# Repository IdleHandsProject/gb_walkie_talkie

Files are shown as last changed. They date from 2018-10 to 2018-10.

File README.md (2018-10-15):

# Ghost Bros Walkie-Talkie
## An open source "Fake" walkie-talkie for Fake Ghost Tours made by my friends in Vancouver.

When I say "Fake" walkie-talkie, what I mean is that this walkie-talkie does not do two way commincation. It actually doesn't even do one way communication(if you don't count the gps). 
This walkie-talkie was designed for my friends at Fake Ghost Tours [FakeGhostTours.com](http://fakeghosttours.com) - real friends not fake friends.

The purpose of the walkie-talkie is to be a GPS guided audio tour of fake ghost stories in Vancouver, British Columbia. 
Watch the video to see how it works, and why it was made. 
https://youtu.be/CiPm3to5vCE

Build Vid (https://youtu.be/CiPm3to5vCE)

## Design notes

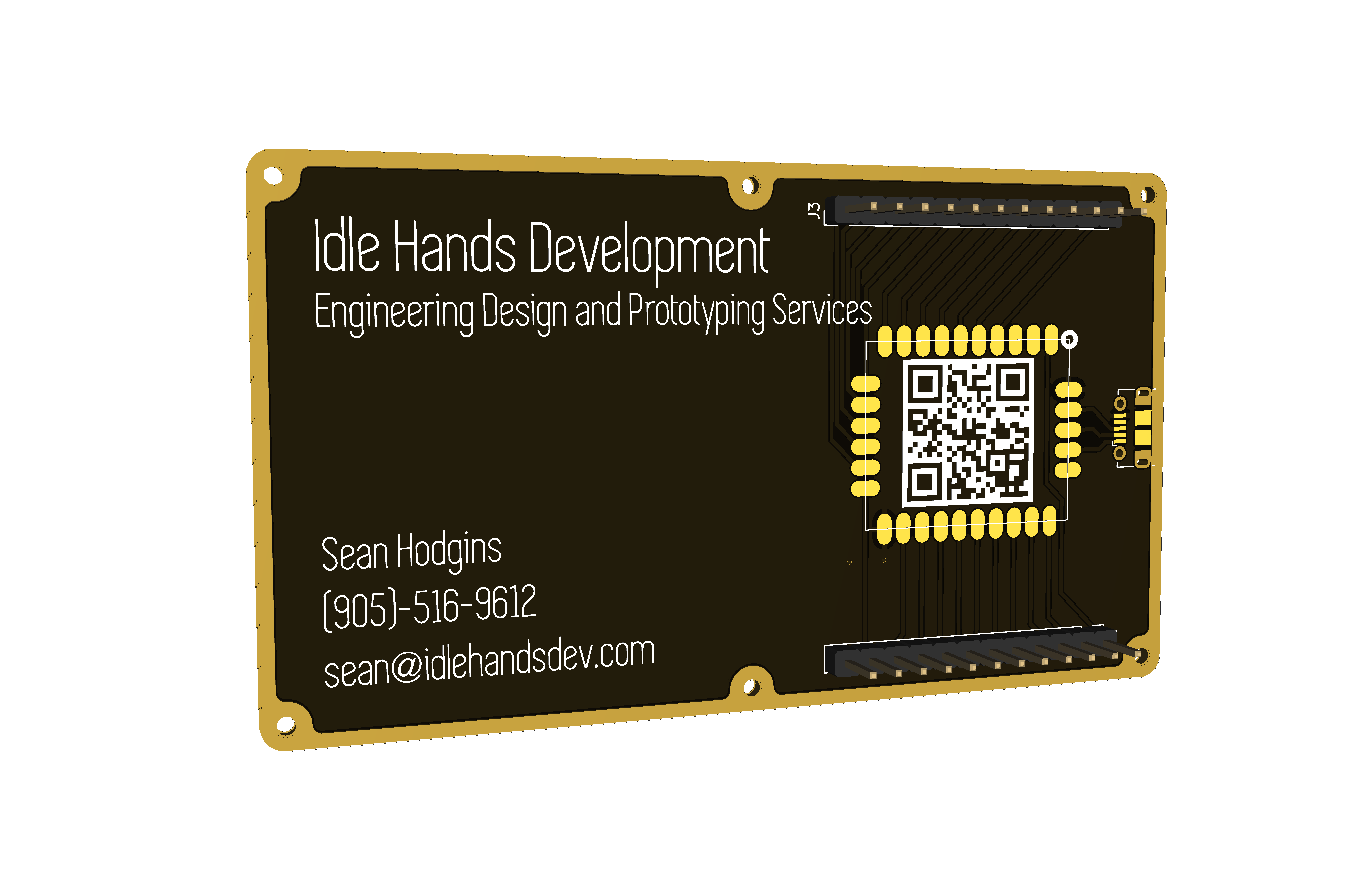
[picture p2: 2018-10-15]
CAD/images/bizcard.png

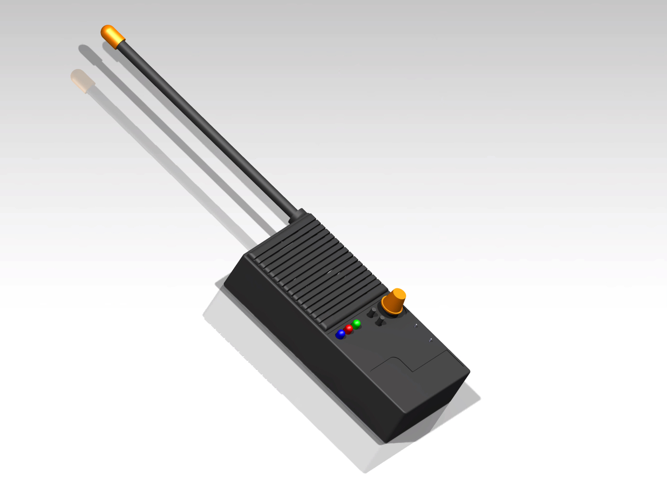
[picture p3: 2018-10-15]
CAD/images/GB_walkie.jpg

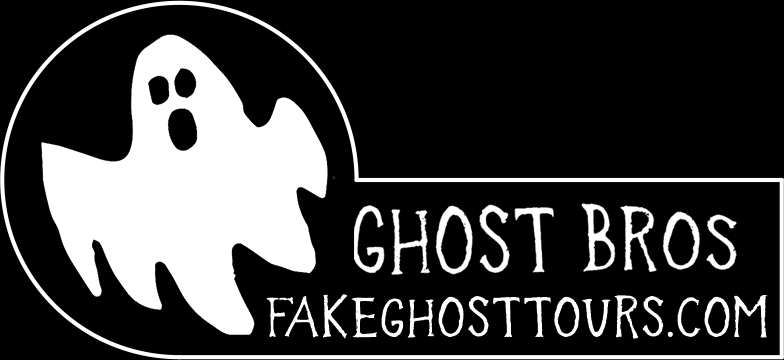
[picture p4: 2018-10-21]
CAD/Drawing/Sticker_Black.png

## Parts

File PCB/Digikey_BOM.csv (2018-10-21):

Manufacturer Part Number | Manufacturer | Digi-Key Part Number | Customer Reference | Reference Designator | Packaging | Part Status | Quantity | Description
BH3AAPC | MPD (Memory Protection Devices) | BH3AA-PC-ND | BT1 |  | Bulk | Active | 1 | BATTERY HOLDER AA 3 CELL PC PIN
CL21F104ZAANNNC | Samsung Electro-Mechanics | 1276-1286-1-ND | C1 C15 C17 C18 |  | Cut Tape (CT) | Active | 4 | CAP CER 0.1UF 25V Y5V 0805
CL21B103KBCNNNC | Samsung Electro-Mechanics | 1276-1078-1-ND | C5 C6 |  | Cut Tape (CT) | Active | 2 | CAP CER 10000PF 50V X7R 0805
CC0402MRX5R5BB106 | Yageo | 311-1729-1-ND | C16 |  | Cut Tape (CT) | Discontinued at Digi-Key | 1 | CAP CER 10UF 6.3V X5R 0402
TMK212BJ105KG-T | Taiyo Yuden | 587-1291-1-ND | C2 C9 C10 C12 C14 C19 C20 |  | Cut Tape (CT) | Active | 7 | CAP CER 1UF 25V X5R 0805
CC0805KRX7R9BB221 | Yageo | 311-1123-1-ND | C11 C13 |  | Cut Tape (CT) | Active | 2 | CAP CER 220PF 50V X7R 0805
EEE-FT0J221AR | Panasonic Electronic Components | P15078CT-ND | C7 C8 |  | Cut Tape (CT) | Active | 2 | CAP ALUM 220UF 20% 6.3V SMD
08051A220KAT2A | AVX Corporation | 478-3736-1-ND | C3 C4 |  | Cut Tape (CT) | Active | 2 | CAP CER 22PF 100V C0G/NP0 0805
35RASMT4BHNTRX | Switchcraft Inc. | SC1488-1-ND | J2 |  | Cut Tape (CT) | Active | 1 | CONN JACK STEREO 3.5MM SMD R/A
693072010801 | Wurth Electronics Inc. | 732-3820-1-ND | J3 |  | Cut Tape (CT) | Active | 1 | CONN MICRO SD CARD HINGED TYPE
614105150721 | Wurth Electronics Inc. | 732-5958-1-ND | J1 |  | Cut Tape (CT) | Active | 1 | CONN RCPT USB TYPE B
MMZ1608B121CTAH0 | TDK Corporation | 445-2164-1-ND | L1 L2 L3 L4 L5 |  | Cut Tape (CT) | Active | 5 | FERRITE BEAD 120 OHM 0603 1LN
GF0666M | CUI Inc. | GF0666M-ND | LS1 |  | Box | Active | 1 | SPEAKER 8OHM 500MW TOP PORT 83DB
CRCW0805100KJNEAC | Vishay Dale | 541-4164-1-ND | R2 R8 R9 R10 R11 R13 R17 |  | Cut Tape (CT) | Active | 7 | RES SMD 100K OHM 5% 1/8W 0805
RC0805JR-07100RL | Yageo | 311-100ARCT-ND | R4 R5 R6 R7 |  | Cut Tape (CT) | Active | 4 | RES SMD 100 OHM 5% 1/8W 0805
RC2012J103CS | Samsung Electro-Mechanics | 1276-5552-1-ND | R12 R15 R18 R19 R20 |  | Cut Tape (CT) | Active | 5 | RES SMD 10K OHM 5% 1/8W 0805
RC0805JR-071KL | Yageo | 311-1.0KARCT-ND | R1 R14 R16 |  | Cut Tape (CT) | Active | 3 | RES SMD 1K OHM 5% 1/8W 0805
RC0805JR-071ML | Yageo | 311-1.0MARCT-ND | R3 |  | Cut Tape (CT) | Active | 1 | RES SMD 1M OHM 5% 1/8W 0805
B3U-1000P | Omron Electronics Inc-EMC Div | SW1020CT-ND | RESET1 |  | Cut Tape (CT) | Active | 1 | SWITCH TACTILE SPST-NO 0.05A 12V
OS102011MS2QN1 | C&K | CKN9565-ND | SW5 |  | Bulk | Active | 1 | SWITCH SLIDE SPDT 100MA 12V
PEC11R-4115F-S0018 | Bourns Inc. | PEC11R-4115F-S0018-ND | SW1 |  | Tray | Active | 1 | ROTARY ENCODER MECHANICAL 18PPR
219-3MST | CTS Electrocomponents | CT2193MST-ND | SW6 |  | Tube | Active | 1 | SWITCH SLIDE DIP SPST 100MA 20V
MJTP1230D | APEM Inc. | 679-2432-ND | SW2 SW3 |  | Bulk | Active | 2 | SWITCH TACTILE SPST-NO 0.05A 12V
AP2112K-1.8TRG1 | Diodes Incorporated | AP2112K-1.8TRG1DICT-ND | U5 |  | Cut Tape (CT) | Active | 1 | IC REG LINEAR 1.8V 600MA SOT25
PAM8302AADCR | Diodes Incorporated | PAM8302AADCRDICT-ND | U3 |  | Cut Tape (CT) | Active | 1 | IC AMP AUDIO 2.5W CLASS D 8SOIC
ABM8G-12.288MHZ-4Y-T3 | Abracon LLC | 535-10902-1-ND | Y1 |  | Cut Tape (CT) | Active | 1 | CRYSTAL 12.2880MHZ 10PF SMD
3314J-1-103E | Bourns Inc. | 3314J-103ECT-ND | RV1 |  | Cut Tape (CT) | Active | 1 | TRIMMER 10K OHM 0.25W J LEAD TOP
151051VS04000 | Wurth Electronics Inc. | 732-5017-ND | GLED |  | Bulk | Active | 1 | LED GREEN DIFFUSED 5MM ROUND T/H
151051RS11000 | Wurth Electronics Inc. | 732-5016-ND | RLED |  | Bulk | Active | 1 | LED RED DIFFUSED 5MM ROUND T/H
151051BS04000 | Wurth Electronics Inc. | 732-5015-ND | BLED |  | Bulk | Active | 1 | LED BLUE DIFFUSED 5MM ROUND T/H

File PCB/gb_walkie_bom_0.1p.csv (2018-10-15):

Component | Description | Part | References | Value | Footprint | Quantity Per PCB | Datasheet | Digikey Part No. | Digikey Part No. | Field8 | Field4 | Field7 | Field6 | Field5
1 | Battery (multiple cells) | Battery | BT1 | Battery | BatteryHolder_BH3AAPC_3xAA | 1 | ~ | BH3AA-PC-ND
2 | Unpolarized capacitor | C_Small | C1 C15 C17 C18 | 0.1uF | C_0805_2012Metric | 4 | ~ | 1276-1286-1-ND
3 | Unpolarized capacitor | C_Small | C5 C6 | 10nF | C_0805_2012Metric | 2 | ~ | 1276-1078-1-ND
4 | Unpolarized capacitor | C_Small | C16 | 10uF | C_0805_2012Metric | 1 | ~ | 311-1729-1-ND
5 | Unpolarized capacitor | C_Small | C2 C9 C10 C12 C14 C19 C20 | 1uF | C_0805_2012Metric | 7 | ~ | 587-1291-1-ND
6 | Unpolarized capacitor | C_Small | C11 C13 | 220pF | C_0805_2012Metric | 2 | ~ | 311-1123-1-ND
7 | Polarised capacitor | CP1_Small | C7 C8 | 220uF | CP_Elec_5x5.3 | 2 | ~ | P15078CT-ND
8 | Unpolarized capacitor | C_Small | C3 C4 | 22pF | C_0805_2012Metric | 2 | ~ | 478-3736-1-ND
9 | LED generic | LED | D1 D2 D3 | LED | LED_D5.0mm | 3 | ~
10 | D Audio Jack, 3 Poles (Stereo / TRS), Grounded Sleeve, Switched Poles (Normalling) | AudioJack3_Ground_Switch | J2 | HPJACK | Jack_3.5mm_35RASMT4BHNTRX_Horizontal | 1 | ~ | SC1488-1-ND
11 | Micro SD Card Socket | Micro_SD_Card | J3 | Micro_SD_Card | microSD_HC_Wuerth_693072010801 | 1 | http://katalog.we-online.de/em/datasheet/693072010801.pdf | 732-3820-1-ND
12 | USB mini/micro connector | USB_OTG | J1 | USB_OTG | USB_Micro-B_Wuerth_614105150721_Vertical | 1 | ~ | 732-5958-1-ND
13 | Solder Jumper, 3-pole, open | SolderJumper_3_Open | JP8 | 1v8EN | SolderJumper-3_P1.3mm_Open_RoundedPad1.0x1.5mm | 1 | ~
14 | Solder Jumper, 3-pole, open | SolderJumper_3_Open | JP6 | MP3RXSEL | SolderJumper-3_P1.3mm_Open_RoundedPad1.0x1.5mm | 1 | ~
15 | Jumper, normally open | Jumper_NO_Small | JP4 JP5 JP7 | RST | SolderJumper-2_P1.3mm_Open_RoundedPad1.0x1.5mm | 3 | ~
16 | Ferrite bead | Ferrite_Bead | L1 L2 | AFLTR | L_0805_2012Metric | 2 | ~ | 445-2164-1-ND
17 | Ferrite bead | Ferrite_Bead | L3 | GFLTR | L_0805_2012Metric | 1 | ~ | 445-2164-1-ND
18 | Ferrite bead | Ferrite_Bead | L4 L5 | SPFLTR | L_0805_2012Metric | 2 | ~ | 445-2164-1-ND
19 | speaker | Speaker | LS1 | Speaker | TerminalBlock_MetzConnect_Type059_RT06302HBWC_1x02_P3.50mm_Horizontal | 1 | ~
20 | Resistor, small symbol | R_Small | R2 R8 R9 R10 R11 R13 R17 | 100K | R_0805_2012Metric | 7 | ~ |  | 541-4164-1-ND
21 | Resistor, small symbol | R_Small | R4 R5 R6 R7 | 100R | R_0805_2012Metric | 4 | ~ |  | 311-100ARCT-ND
22 | Resistor, small symbol | R_Small | R12 R15 R18 R19 R20 | 10K | R_0805_2012Metric | 5 | ~ |  | 1276-5552-1-ND
23 | Resistor, small symbol | R_Small | R1 R14 R16 | 1K | R_0805_2012Metric | 3 | ~ | 311-1.0KARCT-ND
24 | Resistor, small symbol | R_Small | R3 | 1M | R_0805_2012Metric | 1 | ~ |  | 311-1.0MARCT-ND
25 | Push button switch, generic, two pins | SW_Push | RESET1 | RESET | SW_SPST_B3U-1000P | 1 |  | SW1020CT-ND
26 | Potentiometer | R_POT | RV1 | R_POT | Potentiometer_Bourns_3314J_Vertical | 1 | ~ | 445-2164-1-ND
27 | Switch, single pole double throw | SW_SPDT | SW5 | POWER | SW_CuK_OS102011MA1QN1_SPDT_Angled | 1 |  | CKN9565-ND
28 | Rotary encoder, dual channel, incremental quadrate outputs, with switch | Rotary_Encoder_Switch | SW1 | Rotary_Encoder_Switch | RotaryEncoder_Alps_EC11E-Switch_Vertical_H20mm | 1 | ~ | PEC11R-4115F-S0018-ND
29 | 3x DIP Switch, Single Pole Single Throw (SPST) switch, small symbol | SW_DIP_x03 | SW6 | SW_DIP_x03 | SW_DIP_SPSTx03_Slide_6.7x9.18mm_W6.73mm_P2.54mm_LowProfile_JPin | 1 |  | CT2193MST-ND
30 | Push button switch, generic, two pins | SW_Push | SW2 SW3 | SW_Push | SW_PUSH_6mm_H13mm | 2
31 | 300mA low dropout linear regulator, shutdown pin, 2.5V-6V input voltage, 1.8V fixed positive output, SOT-23-5 package | AP2127K-1.8 | U5 | AP2127K-1.8 | SOT-23-5 | 1 | https://www.diodes.com/assets/Datasheets/AP2127.pdf | AP2112K-1.8TRG1DICT-ND
32 |  | CODECODER-VS1053B(LQFP48) | U2 | CODECODER-VS1053B(LQFP48) | LQFP-48_7x7mm_P0.5mm | 1 | VS1053B MP3/WAV/OGG/MIDI Player & Recorder _CODEC_ Chip |  |  | VS1053B-L | Unavailable | None | VLSI | LQFP-48 VLSI
33 |  | FGPMM0PA6H | U4 | FGPMM0PA6H | FGPMMOPA6H | 1
34 | 2.5W Filterless Class-D Mono Audio Amplifier, SOIC-8 | PAM8302AAD | U3 | PAM8302AAD | SOIC-8_3.9x4.9mm_P1.27mm | 1 | https://www.diodes.com/assets/Datasheets/PAM8302A.pdf | PAM8302AADCRDICT-ND
35 |  | SAMD21_MOD | U1 | SAMD21_MOD | SAMD_HCC_G_FOOT | 1
36 | Four pin crystal (GND on pins 2 and 4), e.g. in SMD package | Crystal_GND24 | Y1 | 12.288MHz | crystal_fa128 | 1 | ~ | 535-10902-1-ND
Component Groups: | 36
Component Count: | 71
Fitted Components: | 71
Number of PCBs: | 1
Total components: | 71
Schematic Version: | 0.1p
Schematic Date: | 2018-10-01
BoM Date: | 10/10/2018 3:36:40 PM
Schematic Source: | \\HODGINSA-LAPTOP\Users\hodginsa\Documents\idlehandsdev\walkietalkie_ghostbros\PCB\gb_walkie.sch
KiCad Version: | Eeschema (5.0.0)

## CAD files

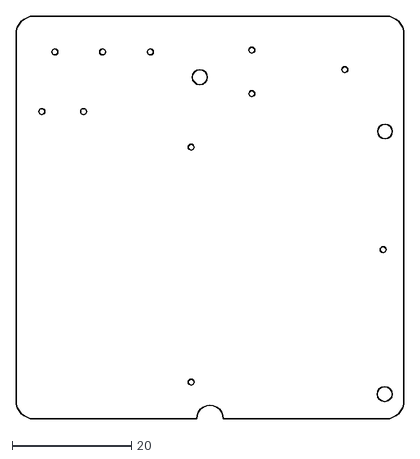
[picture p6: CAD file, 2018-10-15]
CAD/Drawing/PCB.dxf
65.0 x 67.5

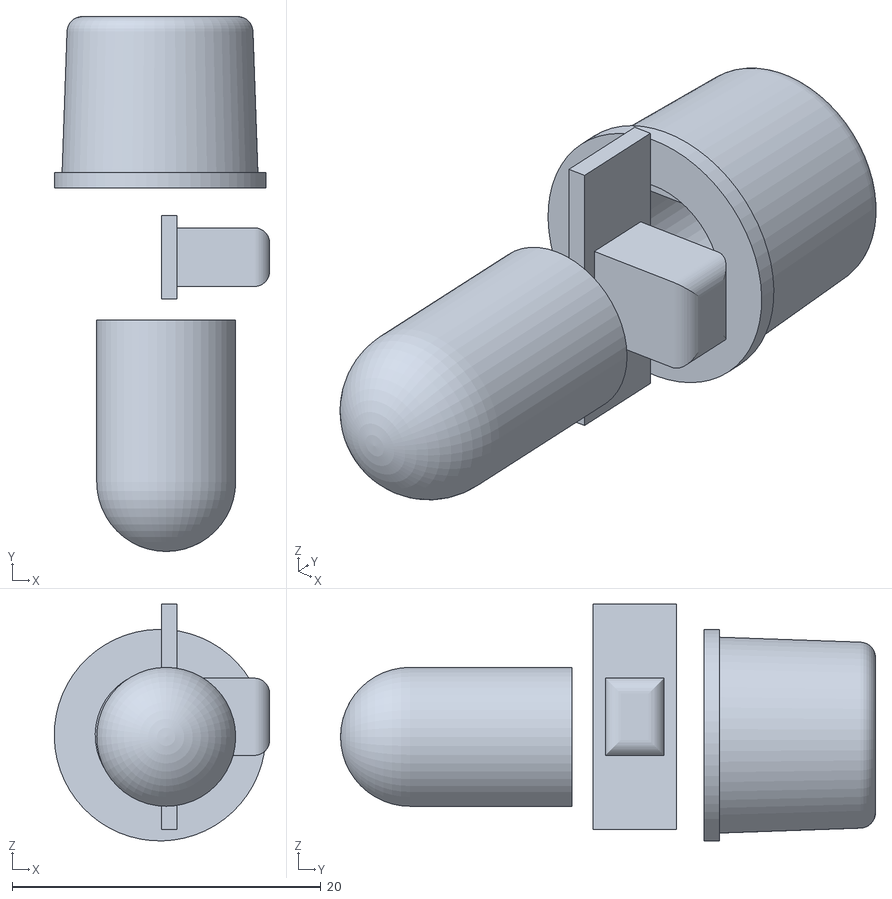
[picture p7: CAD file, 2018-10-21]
CAD/STL/Accessories.stl
14.0 x 34.7 x 15.3

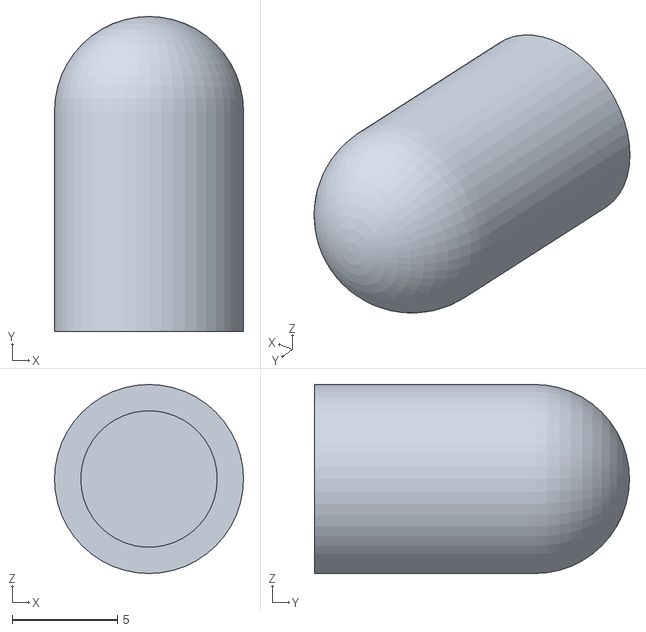
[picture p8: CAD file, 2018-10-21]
CAD/STL/Thingi/ANTCAP.stl
9.00 x 15.0 x 9.00

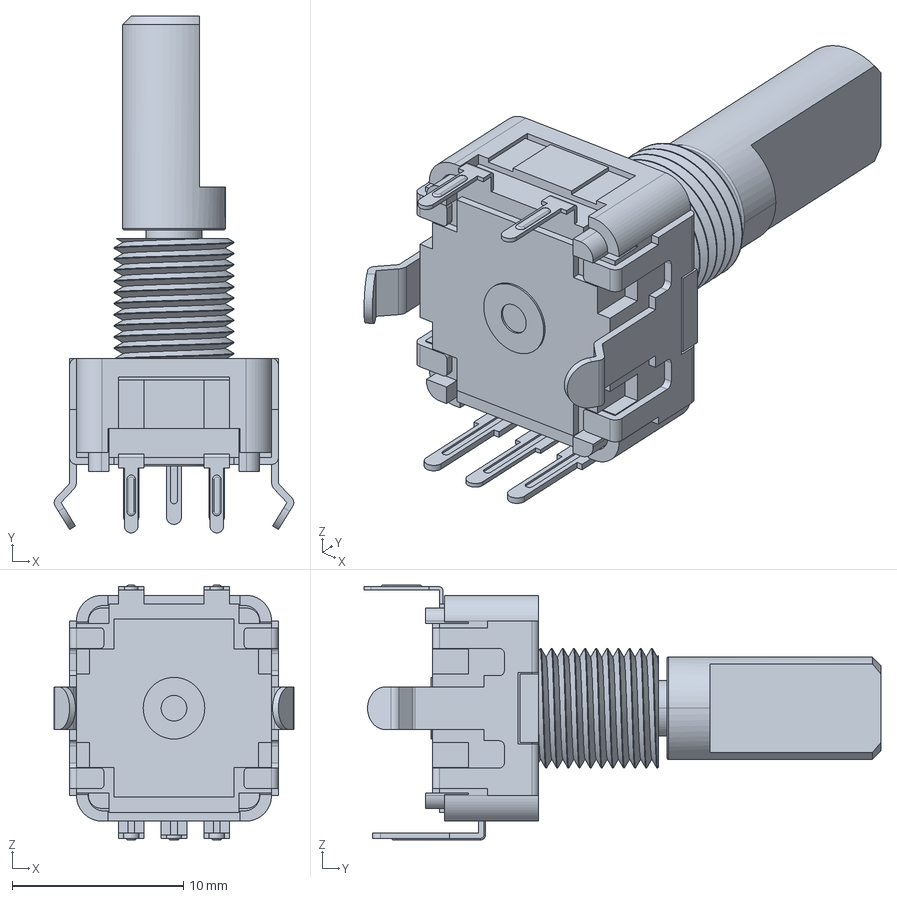
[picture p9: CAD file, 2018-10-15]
CAD/STP/pec11r-4x20f-sxxxx.stp
14.0 x 30.2 x 14.9 mm

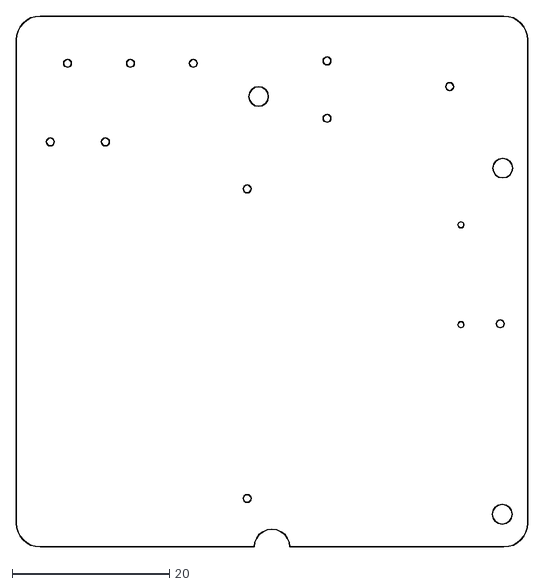
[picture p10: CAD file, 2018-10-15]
PCB/PCB.dxf
65.0 x 67.5

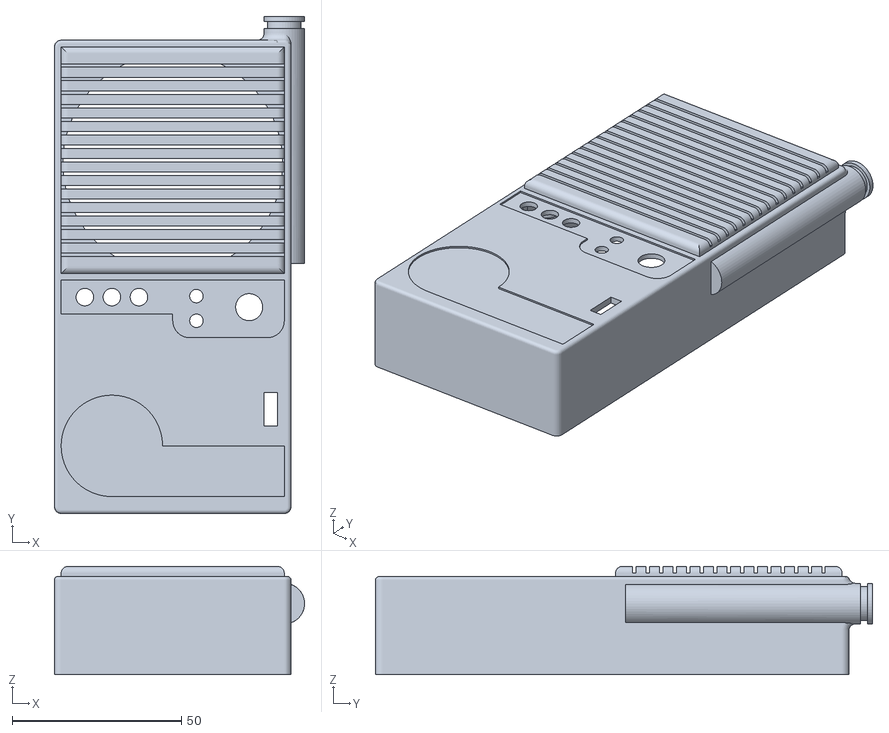
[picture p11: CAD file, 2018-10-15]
CAD/STL/FrontBody.stl
74.0 x 147.0 x 32.0

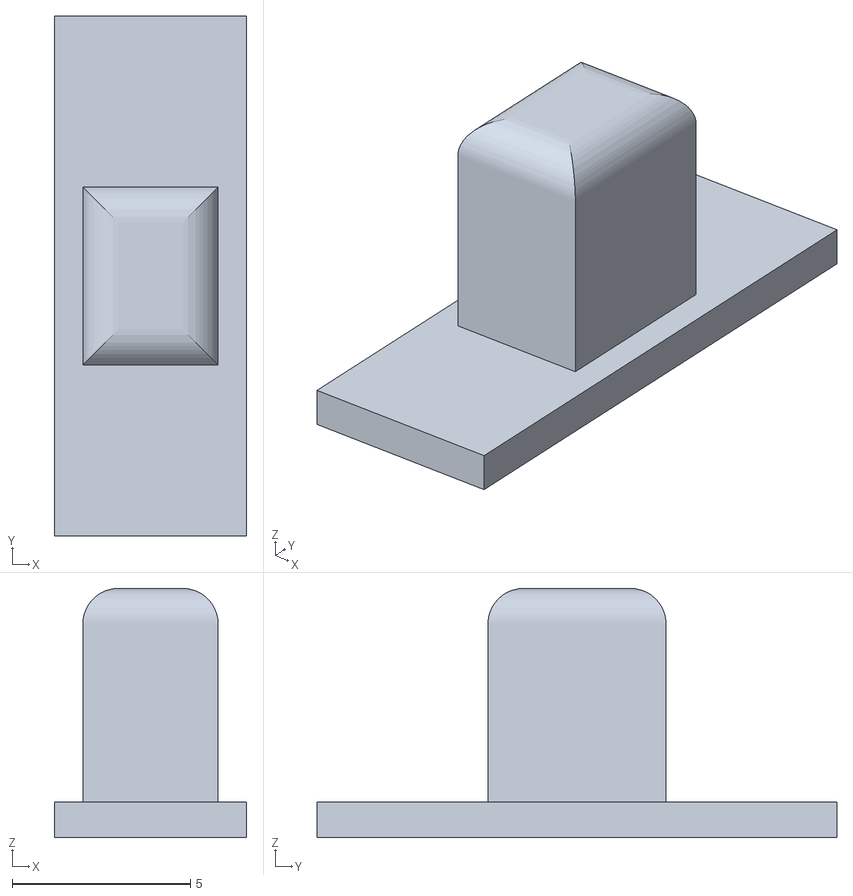
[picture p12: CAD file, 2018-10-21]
CAD/STL/Thingi/SwitchCap.stl
5.40 x 14.6 x 7.00

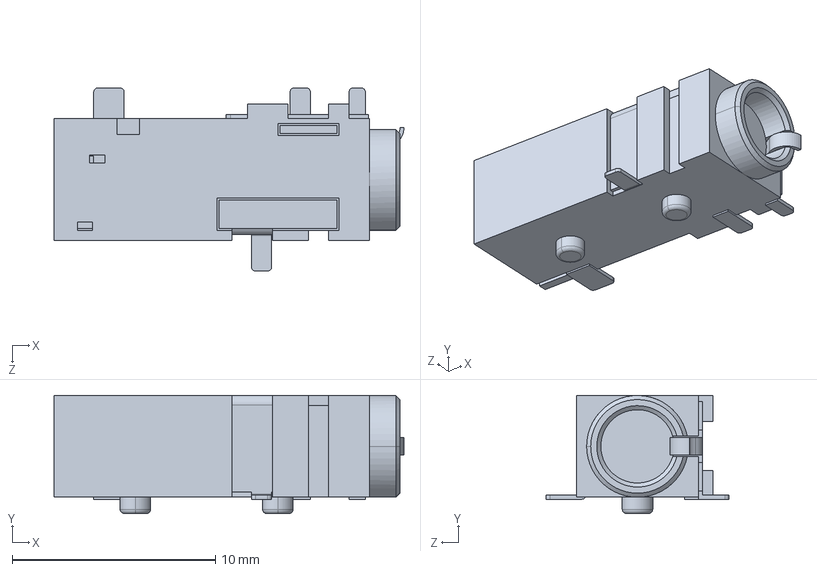
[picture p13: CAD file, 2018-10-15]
CAD/STP/CUI_SJ-43514-SMT-TR.step
17.2 x 5.80 x 9.00 mm

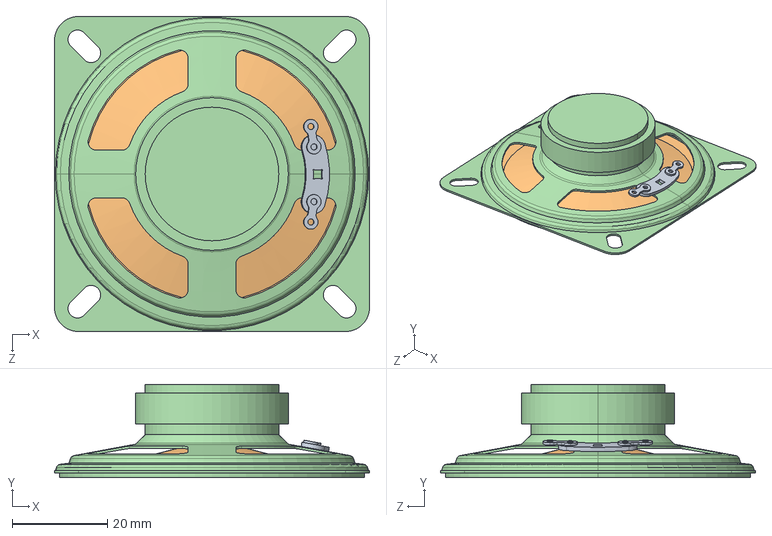
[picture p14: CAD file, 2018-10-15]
CAD/STP/CUI_GF0666M.step
66.0 x 19.5 x 66.0 mm

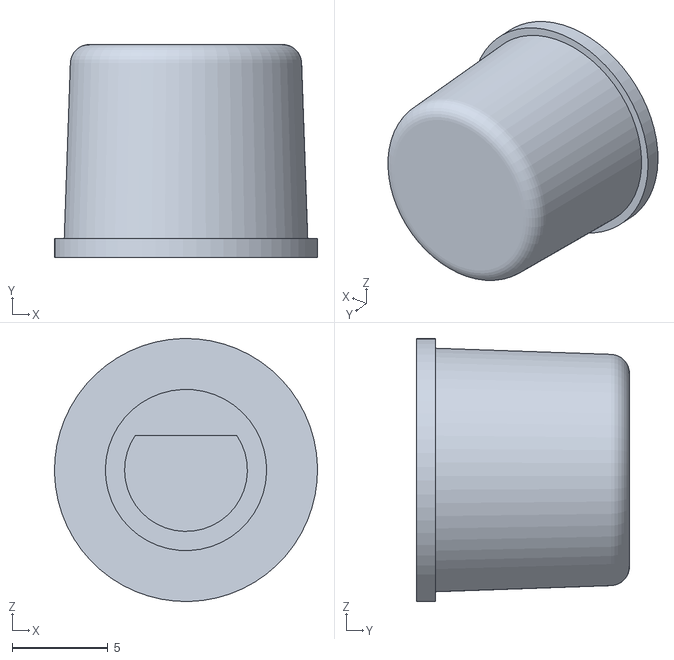
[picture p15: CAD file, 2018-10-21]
CAD/STL/Thingi/Knob.stl
13.7 x 11.1 x 13.7

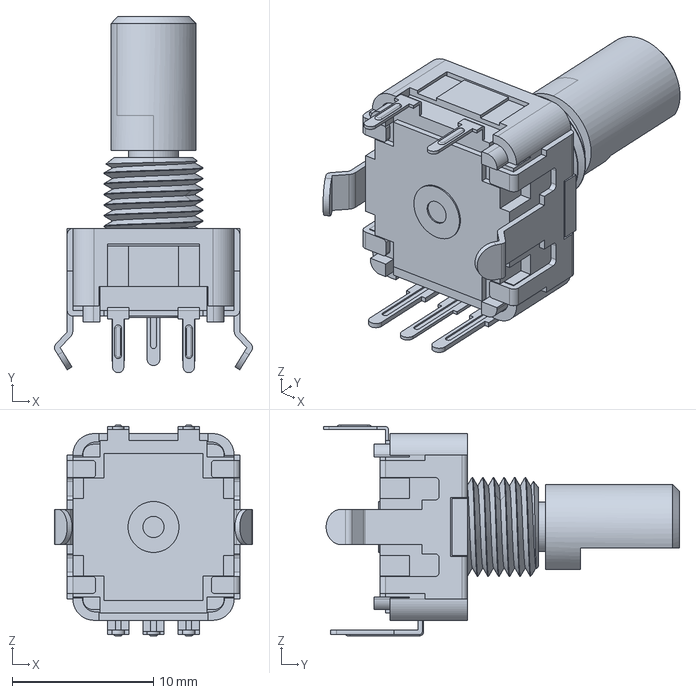
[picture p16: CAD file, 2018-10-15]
CAD/STP/pec11r-4x15f-sxxxx.stp
14.0 x 25.2 x 14.9 mm

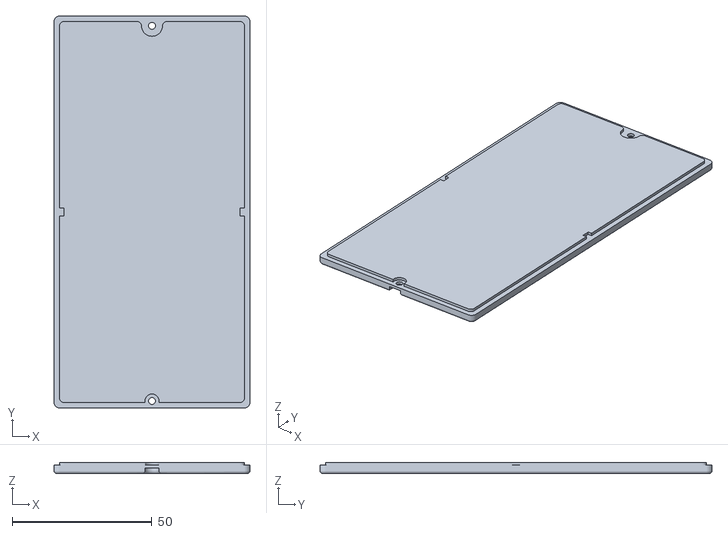
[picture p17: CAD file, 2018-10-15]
CAD/STL/Thingi/BackBody.stl
70.0 x 140.0 x 4.00

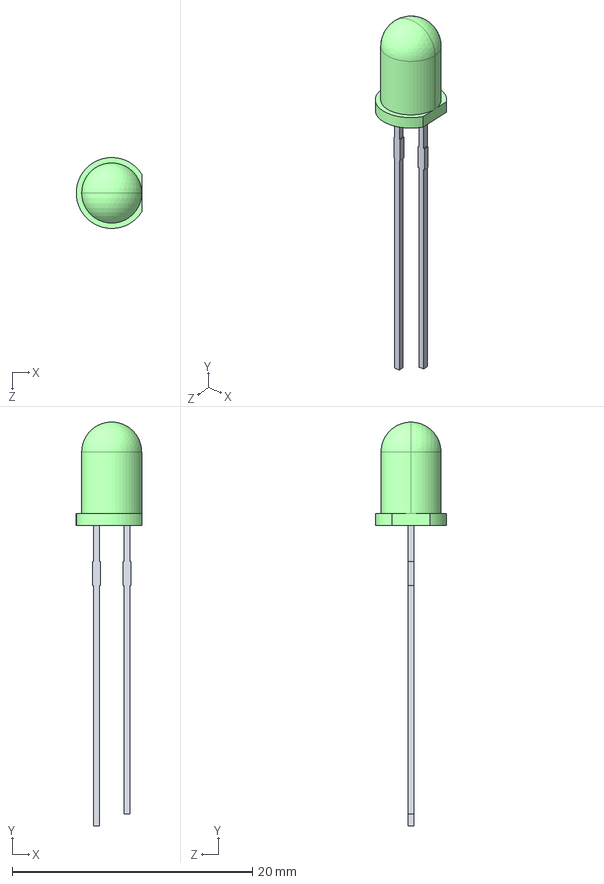
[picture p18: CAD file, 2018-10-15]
CAD/STP/LED_G_5mm_2pin.STEP
5.45 x 33.6 x 5.90 mm

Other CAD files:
CAD/Drawing/Sticker.dwg
CAD/STL/Thingi/FrontBody.stl
CAD/STP/LED_R_5mm_2pin.STEP
CAD/STP/LED_Y_5mm_2pin.STEP
CAD/STP/LED_B_5mm_2pin.STEP
CAD/STP/BC4AAW.STEP
CAD/STP/BH3AAPC.STEP
CAD/STP/OS103011MS8QP1.stp
CAD/STP/micro SD Card Slot.step
CAD/STP/tactileswitch-long.STEP

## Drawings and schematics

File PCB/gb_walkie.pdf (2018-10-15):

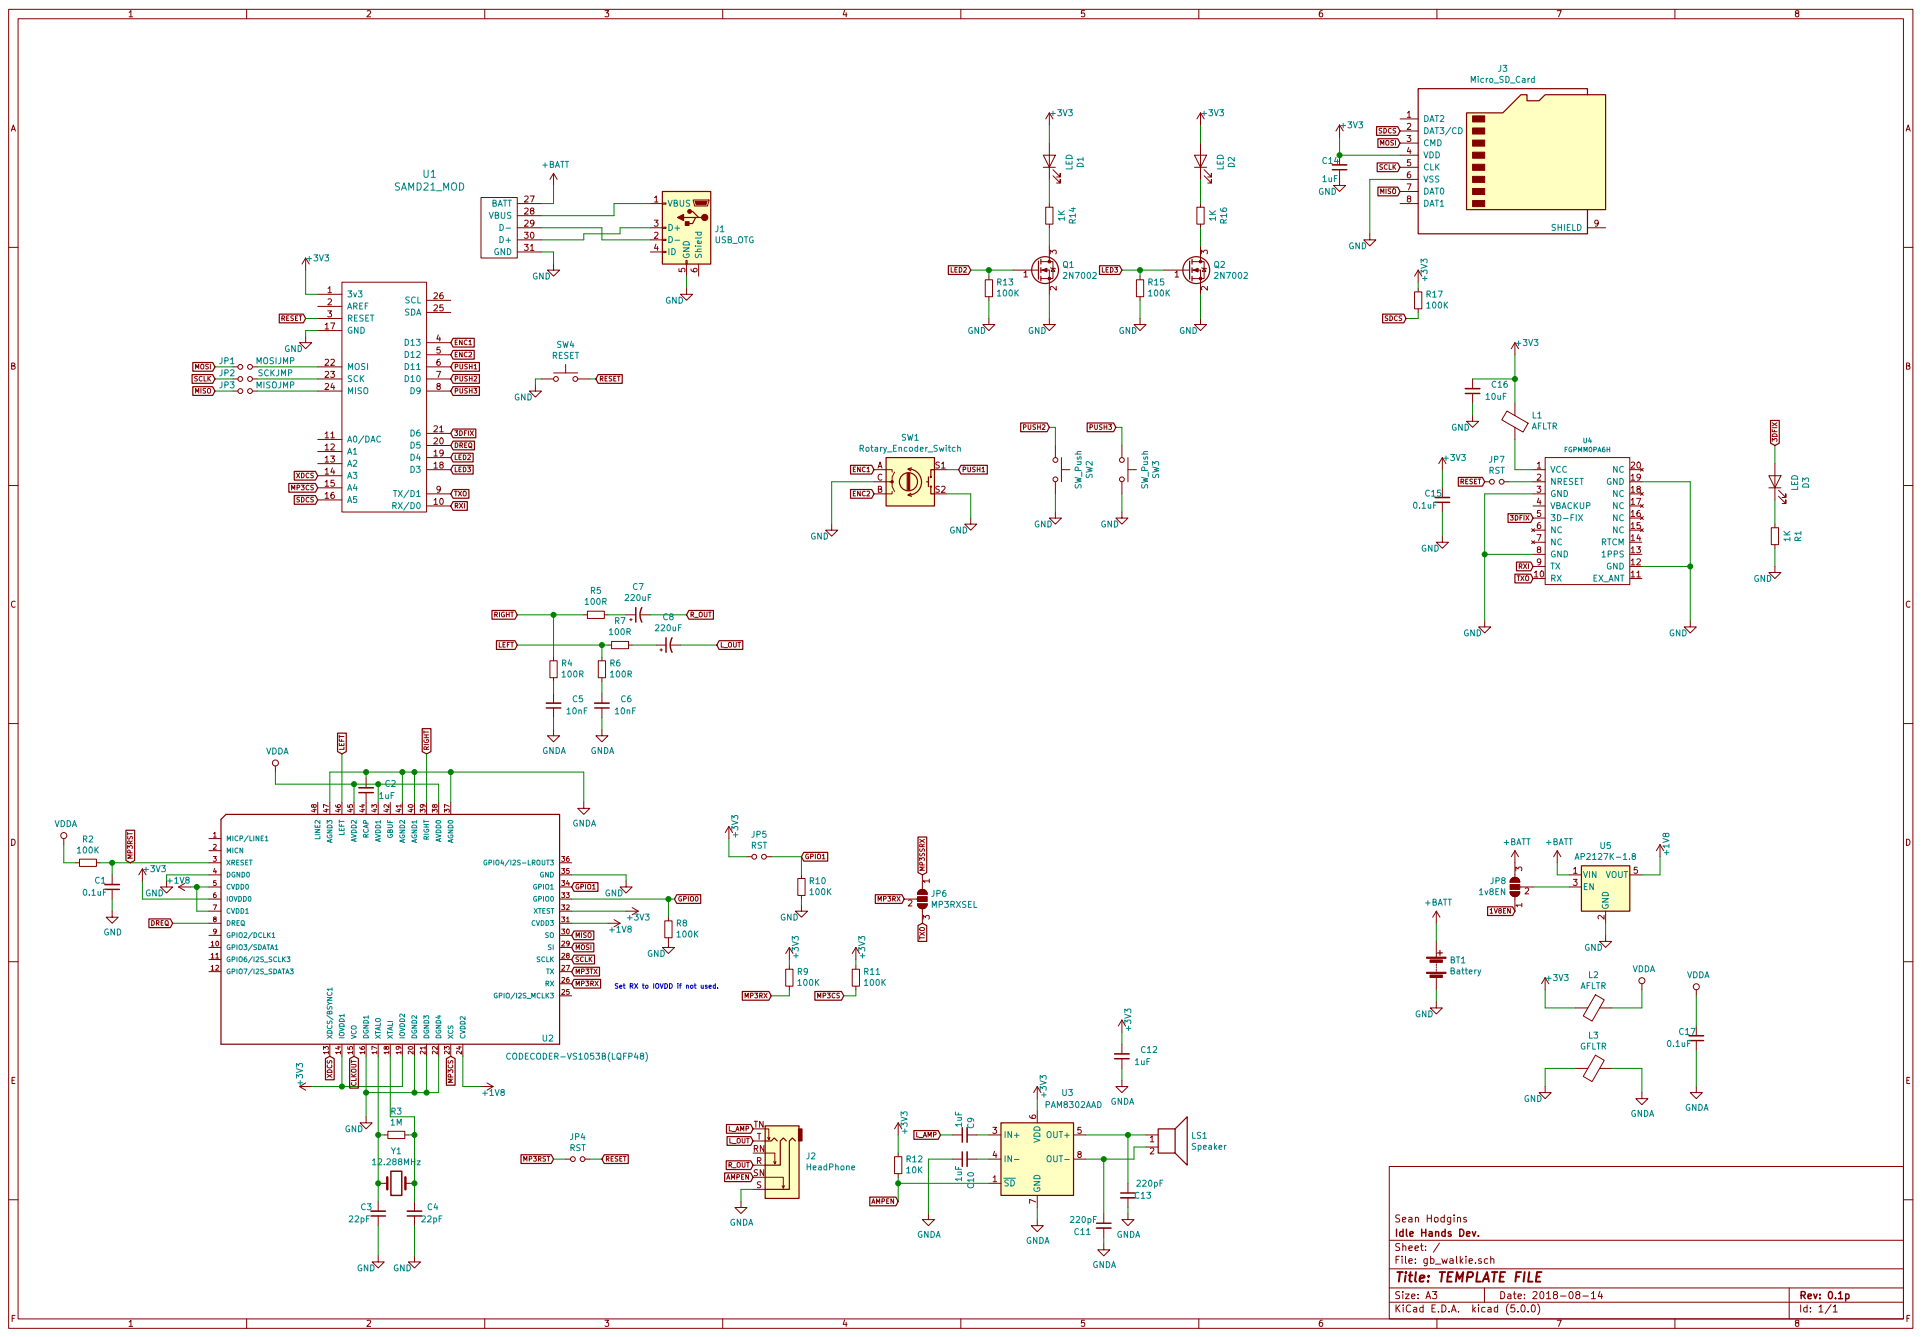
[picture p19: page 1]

2 EN 3 VOUT 5 U5 AP2127K-1.8 BT1 Battery GND

Idle Hands Dev. Sean Hodgins

File: gb_walkie.sch Sheet: /
Id: 1/1 Title: TEMPLATE FILE

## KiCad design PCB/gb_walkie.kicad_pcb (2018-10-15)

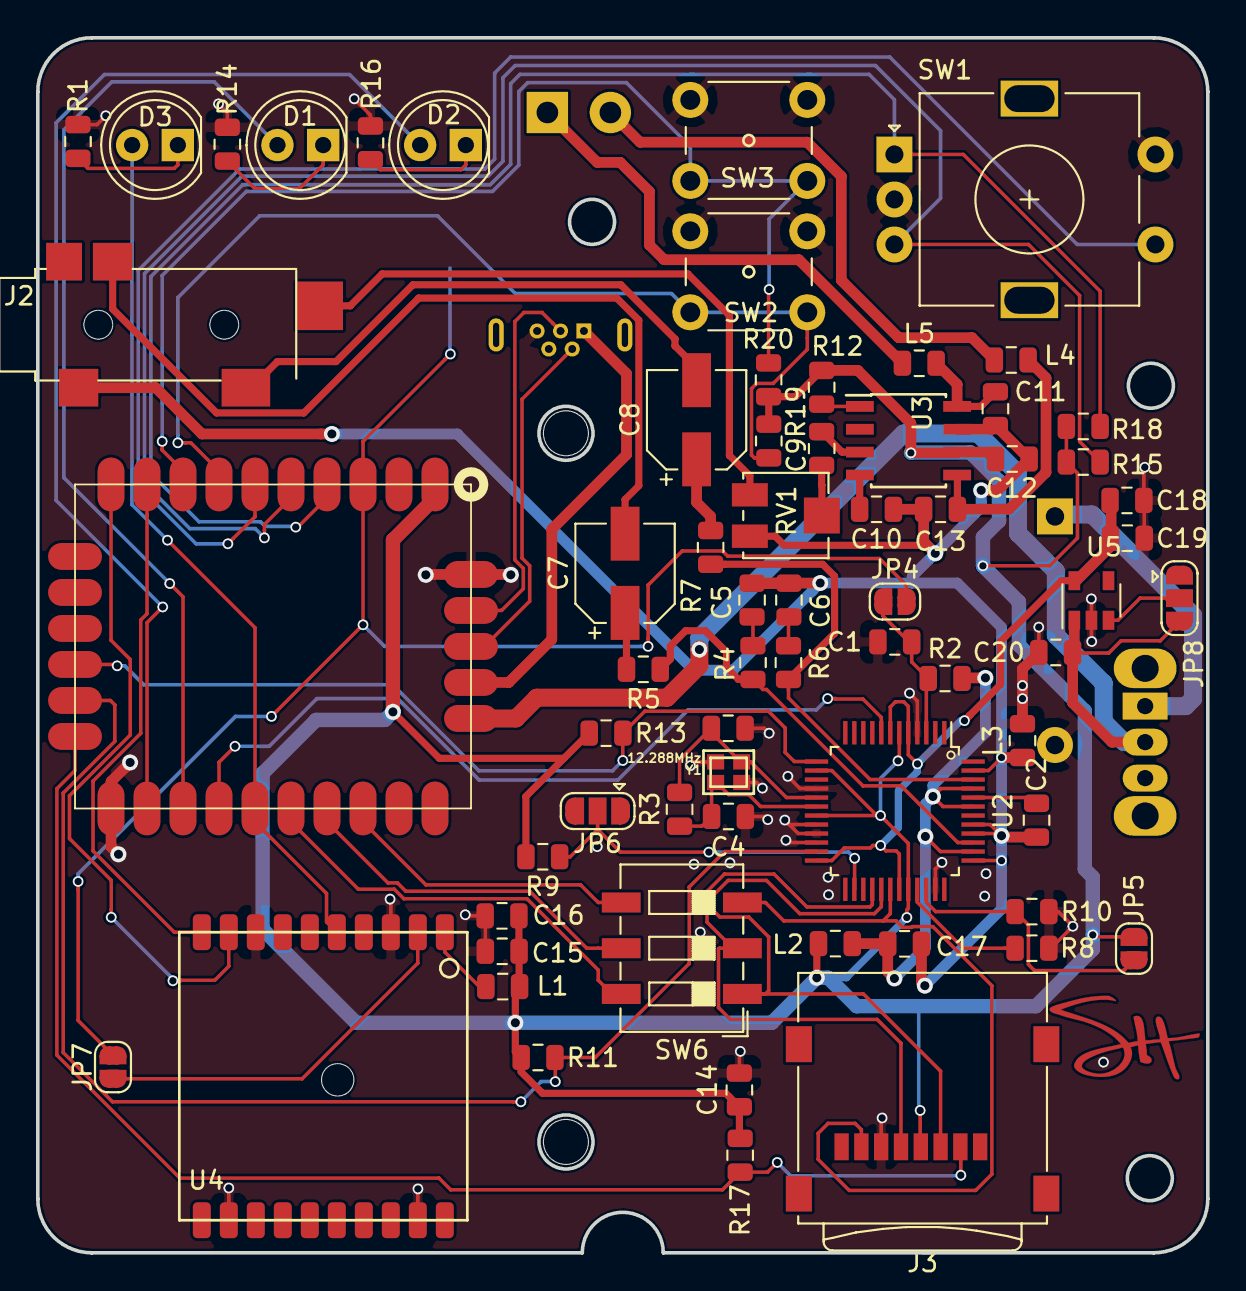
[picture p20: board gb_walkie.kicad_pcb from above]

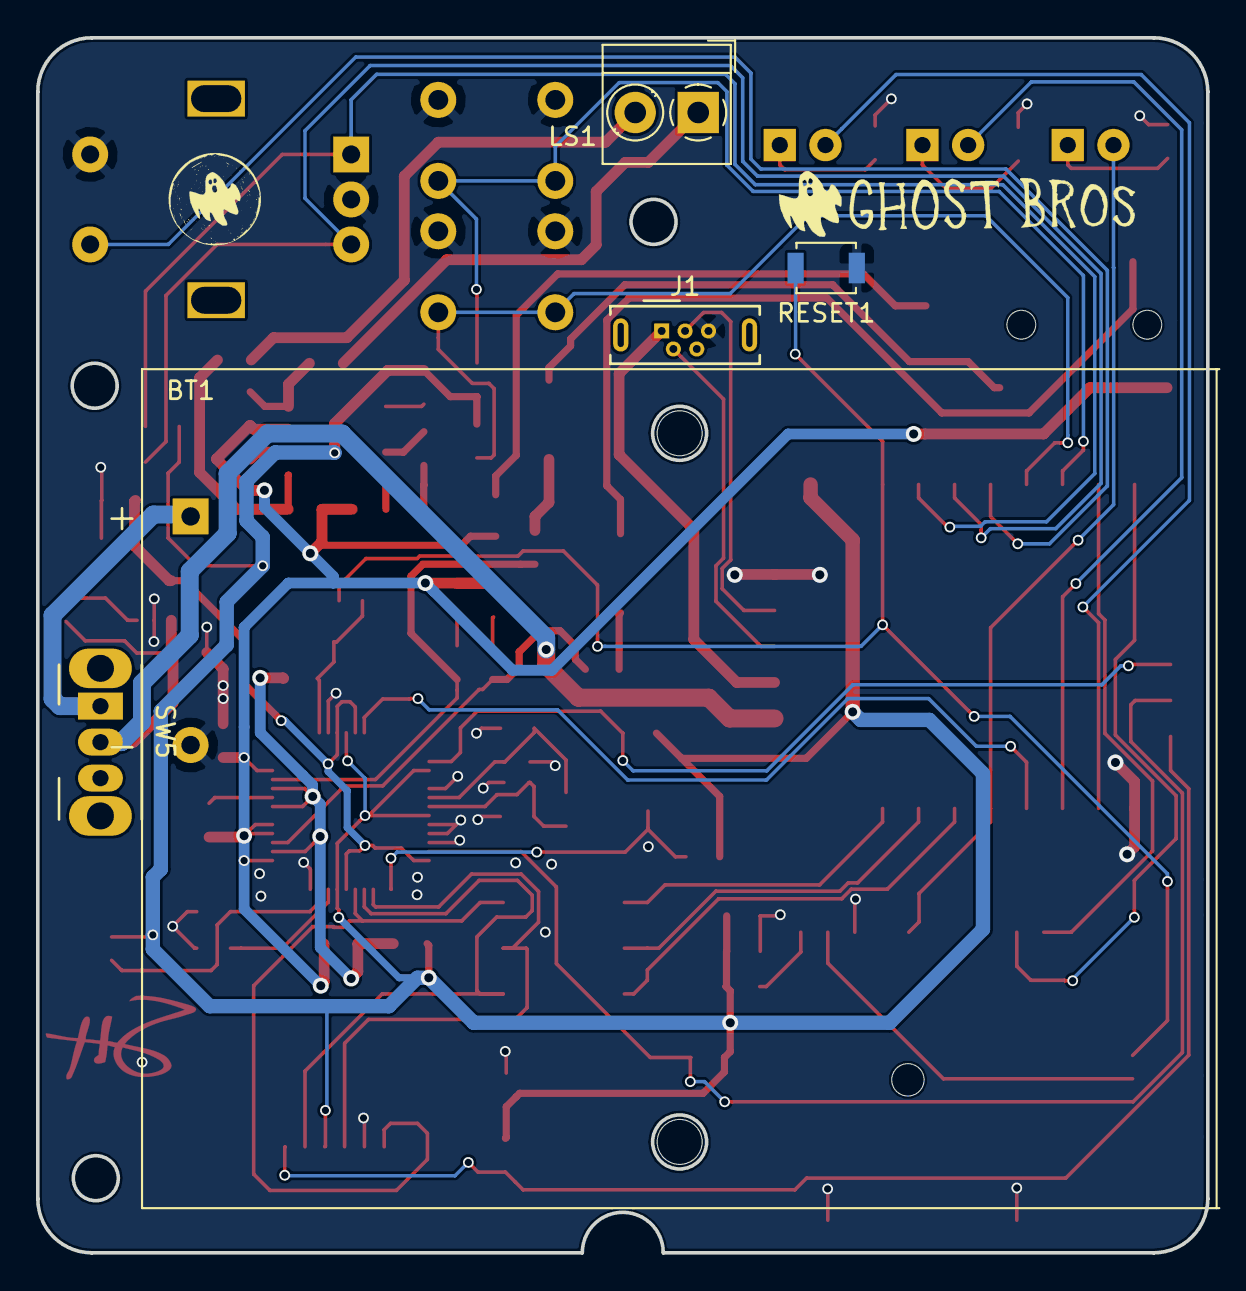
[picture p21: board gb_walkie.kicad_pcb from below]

Board: 2 copper layers, 65.0 x 67.5 mm, 71 parts (5 on the bottom side), 61 nets.

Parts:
BT1: Battery; BatteryHolder_BH3AAPC_3xAA
C1, C15, C17, C18: 0.1uF; C_0805_2012Metric
C2, C9, C10, C12, C14, C19, C20: 1uF; C_0805_2012Metric
C3, C4: 22pF; C_0805_2012Metric
C5, C6: 10nF; C_0805_2012Metric
C7, C8: 220uF; CP_Elec_5x5.3
C11, C13: 220pF; C_0805_2012Metric
C16: 10uF; C_0805_2012Metric
D1, D2, D3: LED; LED_D5.0mm
J1: USB_OTG; USB_Micro-B_Wuerth_614105150721_Vertical
J2: HPJACK; Jack_3.5mm_35RASMT4BHNTRX_Horizontal
J3: Micro_SD_Card; microSD_HC_Wuerth_693072010801
JP4, JP5, JP7: RST; SolderJumper-2_P1.3mm_Open_RoundedPad1.0x1.5mm
JP6: MP3RXSEL; SolderJumper-3_P1.3mm_Open_RoundedPad1.0x1.5mm
JP8: 1v8EN; SolderJumper-3_P1.3mm_Open_RoundedPad1.0x1.5mm
L1, L2: AFLTR; L_0805_2012Metric
L3: GFLTR; L_0805_2012Metric
L4, L5: SPFLTR; L_0805_2012Metric
LS1: Speaker; TerminalBlock_MetzConnect_Type059_RT06302HBWC_1x02_P3.50mm_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
R1, R14, R16: 1K; R_0805_2012Metric
R2, R8, R9, R10, R11, R13, R17: 100K; R_0805_2012Metric
R3: 1M; R_0805_2012Metric
R4, R5, R6, R7: 100R; R_0805_2012Metric
R12, R15, R18, R19, R20: 10K; R_0805_2012Metric
RESET1: RESET; SW_SPST_B3U-1000P
RV1: R_POT; Potentiometer_Bourns_3314J_Vertical
SW1: Rotary_Encoder_Switch; RotaryEncoder_Alps_EC11E-Switch_Vertical_H20mm
SW2, SW3: SW_Push; SW_PUSH_6mm_H13mm
SW5: POWER; SW_CuK_OS102011MA1QN1_SPDT_Angled
SW6: SW_DIP_x03; SW_DIP_SPSTx03_Slide_6.7x9.18mm_W6.73mm_P2.54mm_LowProfile_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
U1: SAMD21_MOD; SAMD_HCC_G_FOOT
U2: CODECODER-VS1053B(LQFP48); LQFP-48_7x7mm_P0.5mm
U3: PAM8302AAD; SOIC-8_3.9x4.9mm_P1.27mm
U4: FGPMM0PA6H; FGPMMOPA6H
U5: AP2127K-1.8; SOT-23-5
Y1: 12.288MHz; crystal_fa128

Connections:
3DFIX: D3.2, U1.21, U4.5
+1V8: C18.2, C19.2, U2.5, U2.7, U2.24, U2.31, U5.5
+3V3: C12.2, C14.2, C15.2, C16.2, J3.4, JP5.1, L1.2, L2.2, R9.2, R11.2, R12.2, R13.2, R15.2, R17.2, R18.2, R19.2, R20.2, U1.1, U2.6, U2.14, U2.19, U2.32, U3.6
+BATT: C20.2, JP8.3, SW5.2, U1.27, U5.1
AMPEN: R12.1, U3.1
DREQ: U1.20, U2.8
ENC1: R18.1, SW1.A, U1.4
ENC2: R15.1, SW1.B, U1.5
GND: BT1.2, C1.1, C3.1, C4.1, C14.1, C15.1, C16.1, C18.1, C19.1, C20.1, J1.5, J3.6, L3.2, R1.1, R8.1, R10.1, R14.1, R16.1, RESET1.1, SW1.C, SW1.S2, SW2.2, SW3.2, U1.17, U1.31, U2.4, U2.16, U2.20, U2.21, U2.22, U2.35, U4.3, U4.8, U4.12, U4.19, U5.2, Y1.2, Y1.4
GNDA: C2.2, C5.1, C6.1, C10.1, C11.2, C12.1, C13.2, C17.1, J2.S, L3.1, RV1.3, U2.37, U2.40, U2.41, U2.47, U3.7
GPIO0: R8.2, U2.33
GPIO1: JP5.2, R10.2, U2.34
LED2: D1.2, U1.19
LED3: D2.2, U1.18
LEFT: R6.2, R7.1, U2.46
L_AMP: J2.TN, RV1.1
L_OUT: C8.2, J2.T
MISO: J3.7, SW6.3, U2.30
MOSI: J3.3, SW6.1, U2.29
MP3CS: R11.1, U1.15, U2.23
MP3RST: C1.2, JP4.1, R2.1, U2.3
MP3RX: JP6.2, R9.1, U2.26
unnamed: BT1.1, SW5.1
unnamed: C2.1, U2.44
unnamed: C3.2, R3.2, U2.17, Y1.1
unnamed: C4.2, R3.1, U2.18, Y1.3
unnamed: C5.2, R4.1
unnamed: C6.2, R6.1
unnamed: C7.1, R5.2
unnamed: C8.1, R7.2
unnamed: C9.1, RV1.2
unnamed: C9.2, U3.3
unnamed: C10.2, U3.4
unnamed: C11.1, L5.2, U3.8
unnamed: C13.1, L4.2, U3.5
unnamed: D1.1, R14.2
unnamed: D2.1, R16.2
unnamed: D3.1, R1.2
unnamed: J1.1, U1.28
unnamed: J1.2, U1.29
unnamed: J1.3, U1.30
unnamed: JP7.2, U4.2
unnamed: JP8.2, U5.3
unnamed: L1.1, U4.1
unnamed: L4.1, LS1.2
unnamed: L5.1, LS1.1
unnamed: SW6.4, U1.24
unnamed: SW6.5, U1.23
unnamed: SW6.6, U1.22
PUSH1: SW1.S1, U1.6
PUSH2: R19.1, SW2.1, U1.7
PUSH3: R20.1, SW3.1, U1.8
RESET: JP4.2, JP7.1, RESET1.2, U1.3
RIGHT: R4.2, R5.1, U2.39
RXI: U1.10, U4.9
R_OUT: C7.2, J2.R
SCLK: J3.5, SW6.2, U2.28
SDCS: J3.2, R17.1, U1.16
TXO: U1.9, U4.10
VDDA: C17.2, L2.1, R2.2, U2.38, U2.43, U2.45
XDCS: R13.1, U1.14, U2.13

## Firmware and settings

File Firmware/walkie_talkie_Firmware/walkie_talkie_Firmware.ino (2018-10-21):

/////////////////////////////////////////////////////////////
/*
   The FIRMWARE for the Ghost Bros Walkie Talkie Prop
   Watch the Build Video HERE -
   It uses GPS to determine your location and cue an audio file specific to that location.
   All audio files must be in the format of 8.3, (8 letters or numbers dot 3 letters or numbers - ex. AAAAA001.MP3)

   Created by Sean Hodgins 10/03/2018

   You can get the audio files from... INSERT WEBSITE
   The SD Card MUST contain the following files:
   intro000.mp3
   place001.mp3 through place013.mp3
   gpsstart.mp3
   gpsfound.mp3

  You can have unlimited (as SD Card permits) "random" sayings. You must declare the amount in the definition "randomTalkNum".
  Random talking can occur when the user is not close to a designated location.
  The random talk files will need to be named as:
  random00.mp3 - random99.mp3
  Do not skip any numbers.
*/


#include <TinyGPS++.h>
#include <SPI.h>
#include <SD.h>
#include <Adafruit_VS1053.h>

#define numLocations 11

#define randomTalkNum 2
int randomTalkPlayed[randomTalkNum] = {0};

//static const
double Loc_Lat[11] = {49.2843991, 49.283803, 49.283784, 49.283575, 49.283151, 49.283020, 49.283246, 49.283368, 49.283331, 49.283481, 49.283738};
//static const
double Loc_Lon[11] = { -123.1088747, -123.106501, -123.106359,  -123.106587, -123.105319, -123.104172, -123.104099, -123.103920, -123.104192, -123.104020, -123.105401};

char* trackLocation[] = {"place001.mp3", "place002.mp3", "place003.mp3", "place004.mp3", "place005.mp3", "place006.mp3", "place007.mp3", "place008.mp3", "place009.mp3", "place010.mp3", "place011.mp3"};

int distanceTo = 0;
int minimumDist = 50;

int CurrDest = 0;
int LastDest = 0;

#define LEDY 3
#define LEDR 4

#define Serial SerialUSB

#define BUTTTOP 9
#define BUTTBOT 10
#define BUTTENC 11

#define ENC1 13
#define ENC2 12
int encoderValue = 290;
int lastEncoded = 0;
int newA = 0;
int sum = 0;


#define XDCS A3
#define MP3CS A4
#define SDCS A5

#define PIN 1

int volume = 30;

// These are the pins used for the Audio
#define VS1053_RESET   -1     // VS1053 reset pin (not used!)
#define VS1053_CS       A4     // VS1053 chip select pin (output)
#define VS1053_DCS     A3     // VS1053 Data/command select pin (output)
#define CARDCS          A5     // Card chip select pin
// DREQ should be an Int pin *if possible* (not possible on 32u4)
#define VS1053_DREQ     5     // VS1053 Data request, ideally an Interrupt pin

Adafruit_VS1053_FilePlayer musicPlayer =
  Adafruit_VS1053_FilePlayer(VS1053_RESET, VS1053_CS, VS1053_DCS, VS1053_DREQ, CARDCS);


int inLocation = 0;
int currLocation = 0;
int notification = 0;
TinyGPSPlus gps;


int leastdistance = 0;

void setup()
{

  Loc_Lat[2] = 45.5540529;
  Loc_Lon[2] = -75.2820992;
  Serial.begin(115200);
  Serial1.begin(9600);
  //while (!Serial);
  pinMode(BUTTENC, INPUT_PULLUP);
  pinMode(BUTTTOP, INPUT);
  pinMode(BUTTBOT, INPUT);
  pinMode(LEDY, OUTPUT);
  pinMode(LEDR, OUTPUT);


  pinMode(ENC1, INPUT);
  pinMode(ENC2, INPUT);
  attachInterrupt(ENC1, updateEncoder, CHANGE);
  attachInterrupt(ENC2, updateEncoder, CHANGE);
  if (! musicPlayer.begin()) { // initialise the music player
    Serial.println(F("Couldn't find VS1053, do you have the right pins defined?"));
    while (1) {
      digitalWrite(LEDR, HIGH);
      delay(500);
      digitalWrite(LEDY, HIGH);
      delay(500);
      digitalWrite(LEDR, LOW);
      delay(500);
      digitalWrite(LEDY, LOW);
      delay(500);
    }
  }
  Serial.println(F("VS1053 found"));
  musicPlayer.setVolume(volume, 0);
  musicPlayer.sineTest(0x44, 200);    // Make a tone to indicate VS1053 is working
  digitalWrite(LEDY, HIGH);
  digitalWrite(LEDR, HIGH);
  delay(500);
  digitalWrite(LEDY, LOW);
  digitalWrite(LEDR, LOW);


  if (!SD.begin(CARDCS)) {
    Serial.println(F("SD failed, or not present"));
    while (1) {
      digitalWrite(LEDY, HIGH);
      delay(500);
      digitalWrite(LEDR, HIGH);
      delay(500);
      digitalWrite(LEDY, LOW);
      delay(500);
      digitalWrite(LEDR, LOW);
      delay(500);
    }
  }
  Serial.println("SD OK!");

  musicPlayer.setVolume(volume, 0);
  musicPlayer.useInterrupt(VS1053_FILEPLAYER_PIN_INT);  // DREQ int




  attachInterrupt(BUTTTOP, PLAY, FALLING);
  attachInterrupt(BUTTBOT, PAUSE, FALLING);
  attachInterrupt(BUTTENC, STOP, FALLING);

  delay(100);

  Serial.println(F("Searching for GPS"));
  musicPlayer.playFullFile("intro000.mp3");

  while (Serial1.available() > 0)
    gps.encode(Serial1.read());
  while (gps.location.isUpdated() == 0) {
    while (Serial1.available() > 0)
      gps.encode(Serial1.read());
    delay(100);
    Serial.println("Waiting for GPS");
    if (musicPlayer.stopped()) {
      //musicPlayer.startPlayingFile("waiting.mp3");
      //delay(100);
    }
  }

  musicPlayer.stopPlaying();
  Serial.println(F("GPS Found"));


}

void loop()
{
  if (musicPlayer.playingMusic == 1) {
    digitalWrite(LEDY, HIGH);
  }
  if (musicPlayer.stopped()) {
    digitalWrite(LEDY, LOW);
  }
  while (Serial1.available() > 0)
    gps.encode(Serial1.read());

  if (musicPlayer.stopped()) {
    if (gps.location.isValid())
    {
      int locationsum = 0;
      leastdistance = 5000000;
      for (int x = 0; x < numLocations; x++) {
        double distanceToLoc = TinyGPSPlus::distanceBetween(gps.location.lat(), gps.location.lng(), Loc_Lat[x], Loc_Lon[x]);
        int MetersTo = distanceToLoc;
        if (MetersTo < leastdistance){
          leastdistance = MetersTo;
        }
        if (MetersTo < 50) {

          locationsum++;
          currLocation = x;
          if (notification == 0) {
            notification = 1;
            Serial.print("In Location :");
            Serial.println(x);
            Serial.print("Distance: ");
            Serial.println(MetersTo);
          }
        }

      }
      if (locationsum > 0) {
        inLocation = 1;
        if (notification == 1) {
          digitalWrite(LEDR, HIGH);
          musicPlayer.sineTest(0x44, 200);
          notification = 2;
        }
      }
      else {
        inLocation = 0;
        digitalWrite(LEDR, LOW);
      }
    }
  }
  delay(100);
  while (musicPlayer.paused()) {
    for (int y = 255; y > 0; y--) {
      analogWrite(LEDY, y);
      delay(5);
    }
    for (int y = 0; y < 255; y++) {
      analogWrite(LEDY, y);
      delay(5);
    }
    pinMode(LEDY, OUTPUT);
  }

}



void DestChange() {

  int buttstate = digitalRead(4);
  while (buttstate == 0) {
    buttstate = digitalRead(4);
  }
  CurrDest = CurrDest + 1;
  if (CurrDest > 3) {
    CurrDest = 0;
  }
  if (LastDest != CurrDest) {

    LastDest = CurrDest;
  }
}

void PLAY() {
  int butt = digitalRead(BUTTTOP);
  while (butt == 0) {
    butt = digitalRead(BUTTTOP);
  }
  Serial.print("Distance: ");
  Serial.println(leastdistance);
  if (musicPlayer.stopped()) {
    if (inLocation == 1) {
      
      musicPlayer.startPlayingFile(trackLocation[currLocation]);
      notification = 0;
      digitalWrite(LEDY, 255);
    }
  }
}

void STOP() {
  int butt = digitalRead(BUTTENC);
  while (butt == 0) {
    butt = digitalRead(BUTTENC);
  }
  musicPlayer.stopPlaying();
  digitalWrite(LEDY, 0);
}

void PAUSE() {
  int butt = digitalRead(BUTTBOT);
  while (butt == 0) {
    butt = digitalRead(BUTTBOT);
  }
  if (! musicPlayer.paused()) {
    Serial.println("Paused");
    musicPlayer.pausePlaying(true);
  } else {
    Serial.println("Resumed");
    musicPlayer.pausePlaying(false);
  }

}

void VChange() {
  if (! musicPlayer.stopped()) {
    if (! musicPlayer.paused()) {
      musicPlayer.pausePlaying(true);
      Serial.print("Volume: ");
      Serial.println(volume);
      if (volume > 0 && volume < 60) {
        musicPlayer.setVolume(volume, 0);
      }
      musicPlayer.pausePlaying(false);
    }
  }
}


void updateEncoder() {
  int MSB = digitalRead(ENC1); //MSB = most significant bit
  int LSB = digitalRead(ENC2); //LSB = least significant bit

  int encoded = (MSB << 1) | LSB; //converting the 2 pin value to single number
  sum  = (lastEncoded << 2) | encoded; //adding it to the previous encoded value

  if (sum == 0b0010 || sum == 0b1101 || sum == 0b1011 || sum == 0b0100) {
    if (encoderValue > 0) {
      encoderValue--;
    }
  }
  if (sum == 0b1110 || sum == 0b1000 || sum == 0b0001 || sum == 0b0111) {
    if (encoderValue < 300) {
      encoderValue++;
    }
  }
  //Serial.println(encoderValue);
  volume = encoderValue / 5;

  VChange();
  lastEncoded = encoded; //store this value for next time
}

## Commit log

2018-10-21 Removed Sprue
    [Accessories.stl]
2018-10-21 updated component part number
    [Digikey_BOM.csv, gb_walkie.sch]
2018-10-21 added thingiverse STLs
    [ANTCAP.stl, BackBody.stl, FrontBody.stl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]
